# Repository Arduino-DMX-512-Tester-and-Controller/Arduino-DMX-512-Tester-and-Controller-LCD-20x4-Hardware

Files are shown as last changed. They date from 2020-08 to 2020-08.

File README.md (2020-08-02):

# **Arduino DMX-512 Tester and Controller**

## **Hardware - LCD 20x4**














***

Herramienta Open Hardware, para pruebas y control de iluminación de espectáculos a través del protocolo [DMX-512](http://es.wikipedia.org/wiki/Digital_Multiplex), ideal para hacer pruebas rápidas en instalaciones fijas o temporales de iluminación, sin la necesidad de instalar consolas de iluminación, interfaces o computadoras en ambientes al intemperie, hostiles o de difícil acceso.

***

Mas informacion en la Wiki

wiki (https://github.com/Arduino-DMX-512-Tester-and-Controller/Arduino-DMX-512-Tester-and-Controller-LCD-20x4-Firmware/wiki)

***

### **Basado en:**

- [Arduino Mega 2560 Rev-3](http://www.arduino.cc/en/Main/ArduinoBoardMega2560)
- [Librería Arduino cuatro universos DMX v0.3 - Deskontrol](http://www.deskontrol.net/blog/libreria-arduino-cuatro-universos-dmx/)
- [Libreria LCD v1.2.1 - Francisco Malpartida](https://bitbucket.org/fmalpartida/new-liquidcrystal/wiki/Home)
- [Simulación en Proteus de Arduino - Microcontrolandos](http://microcontrolandos.blogspot.mx/2012/12/arduino-componentes-para-o-proteus.html)
- [Encoder](http://www.robodosis.net/2013/01/encoder-rotativo-mecanico-con-pic16f877a_2.html)

***

- Esquemático y PCB en Proteus v8.0 SP1
- LCD de 4x20 con backlight y contraste controlado por software
- Alimentación desde USB, baterías o fuente de alimentación externa
- Encoder para navegacion entre menu
- Teclado numérico 4x4
- Interruptor de on/off
- Salida DMX desde bornera, XLR de 3 pin y XLR de 5 pin
- Leds de estado de salida DMX
- Simulación en Proteus v7.7 SP2 y v8.0 SP1
- Esquemático y PCB en Proteus v8.0 SP1
- Aclarar que para este proyecto se utilizó un Arduino Mega hecho en China
- Regulador para fuente externa, el arduino se calienta
- Bornera para salida de fuente regulada de 5V para uso general
- Led para salida de fuente regulada
- Botón de reset
- Opto acoplado a salida de dmx
- Convertidor de DC/DC para aislamiento de DMX
- SW de palanca para invertir polaridad de salida de DMX
- Jumper default eeprom en pin 9
- Driver para luz led como lampara
- SW para Key Light
- SW para Ext Light
- Espaciadores para fijación
- Leyendas de conexión
- Fuente externa, el arduino se calentaba

***

### **Changelog**

- AGREGADO   - los bordes para la union del acrílico
- ELIMINADO  - base de teclado, queda sobre el acrílico
- AGREGADO   - jack de DC para alimentacion
- AGREGADO   - tornillo entre los conectores para agregar soporte
- CORREGIDO  - bornera de voltaje lateral metera mas
- CORREGIDO  - posición de SW esta al revés, cambiar leyenda en pcb

***

### **Firmware**

- Simulacion en Proteus v7.7 SP2
- Librerias:
  - Arduino: https://geekelectronica.com/simular-arduino-con-proteus/
- Firmware v1.8 a v2.2

***

### **Simulador**

- Hardware v0.6 to v0.8
- Firmware v1.6 to v2.2

***

### **Esquematico**

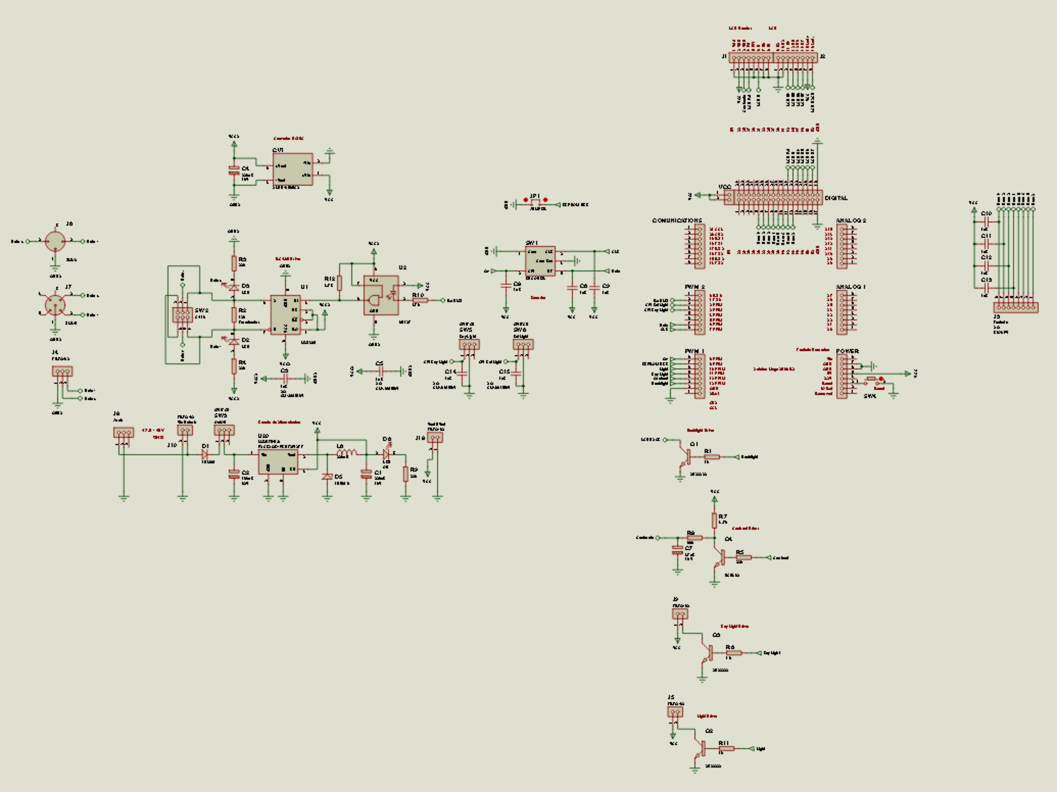
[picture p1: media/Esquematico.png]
Esquematico


***

### **PCB**

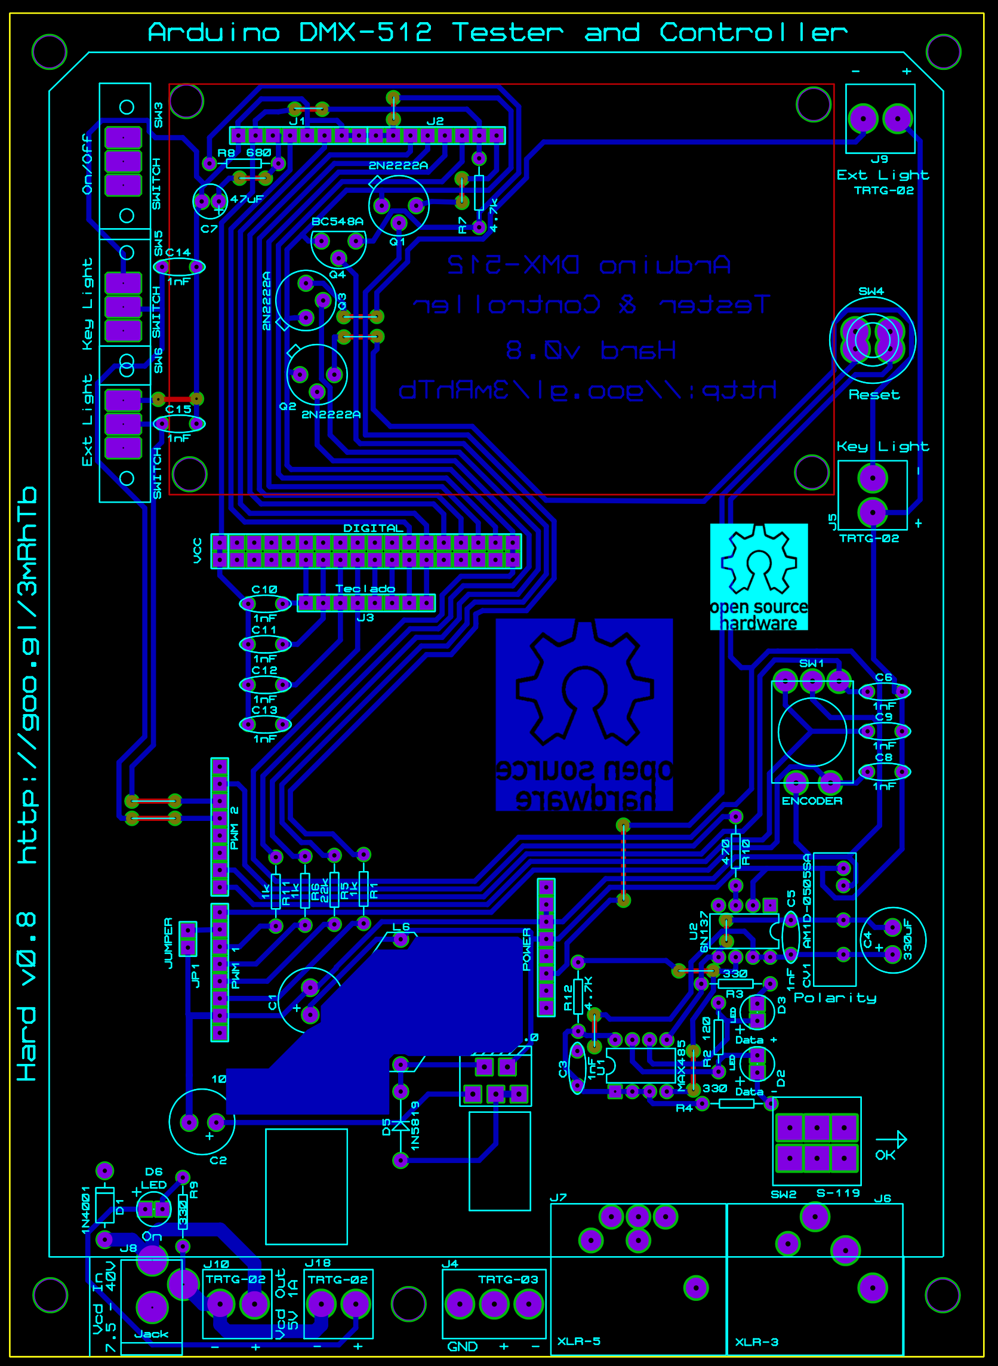
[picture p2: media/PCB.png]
PCB


***

### **Simulador**

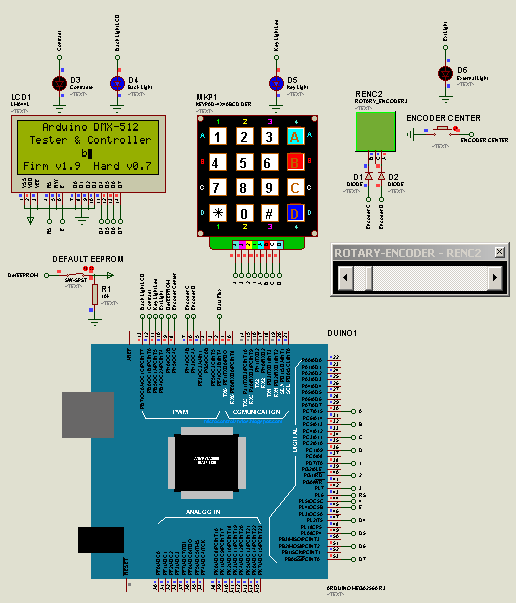
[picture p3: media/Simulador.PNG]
Simulador


***

## **Licenciamiento:**



[Open Source Hardware (OSHW) v1.0](https://github.com/Arduino-DMX-512-Tester-and-Controller/Arduino-DMX-512-Tester-and-Controller-LCD-20x4-Hardware/blob/master/LICENCE.md)

***

## **Autor:**

- Daniel Becerril
- Copyright (C) 2015

Email
Facebook (https://www.facebook.com/daniel.3514)
Facebook (https://www.facebook.com/ArduinoDMX512TesterController)
Twitter (https://twitter.com/daniel3514)
Instructables (http://www.instructables.com/id/Arduino-DMX-512-Tester-and-Controller/)
Hack a Day (https://hackaday.io/project/5342-arduino-dmx-512-tester-and-controller)
Youtube (https://www.youtube.com/watch?v=TxBHMpAWDSY)
Tech Inside (https://techinsideblog.wordpress.com/)
GitHub (https://github.com/Arduino-DMX-512-Tester-and-Controller)
Hackster (https://www.hackster.io/daniel3514/arduino-dmx-512-tester-controller-977c89)

***

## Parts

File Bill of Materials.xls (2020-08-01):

 |  |  |  |  |  | USD | USD
 |  |  |  |  |  |  | $88.72
Category | Quantity | References | Value | Provider | Stock Code | Unit Cost | Total Cost
Capacitors | 2 | C1,C4 | 330uF/16V | www.agelectronica.com | CE-330/16V | $0.09 | $0.18
Capacitors | 1 | C2 | 100uF/63V | www.agelectronica.com | CE-100/63V | $0.09 | $0.09
Capacitors | 11 | C3,C5-C6,C8-C15 | 1nF | www.agelectronica.com | CM-.001/50V | $0.07 | $0.77
Capacitors | 1 | C7 | 47uF/16V | www.agelectronica.com | CE-47/16V | $0.09 | $0.09
Resistors | 3 | R1,R6,R11 | 1k | www.agelectronica.com |  | $0.04 | $0.12
Resistors | 1 | R2 | 120 | www.agelectronica.com |  | $0.04 | $0.04
Resistors | 3 | R3-R4,R9 | 330 | www.agelectronica.com |  | $0.04 | $0.12
Resistors | 1 | R5 | 22k | www.agelectronica.com |  | $0.04 | $0.04
Resistors | 1 | R7 | 4.7k | www.agelectronica.com |  | $0.04 | $0.04
Resistors | 1 | R8 | 680 | www.agelectronica.com |  | $0.04 | $0.04
Resistors | 1 | R10 | 470 | www.agelectronica.com |  | $0.04 | $0.04
Resistors | 1 | R12 | 4.7K | www.agelectronica.com |  | $0.04 | $0.04
Integrated Circuits | 1 | U1 | MAX485 | www.agelectronica.com | SP485CS | $1.18 | $1.18
Integrated Circuits | 1 | U2 | 6N137 | es.aliexpress.com | 6N137 | $0.39 | $0.39
Integrated Circuits | 1 | U20 | LM2575-5.0 | www.agelectronica.com | LM2575T-5.0 | $2.21 | $2.21
Transistors | 3 | Q1-Q3 | 2N2222A | www.agelectronica.com | NTE123AP | $0.83 | $2.49
Transistors | 1 | Q4 | BC548A | www.agelectronica.com | NTE199 | $1.03 | $1.03
Diodes | 1 | D1 | 1N4001 | www.agelectronica.com | 1N4001 | $0.05 | $0.05
Diodes | 3 | D2-D3,D6 | LED | www.agelectronica.com | LED-R3D-AD-R30 | $0.04 | $0.12
Diodes | 1 | D5 | 1N5819 | www.agelectronica.com | 1N5819 | $0.09 | $0.09
Miscellaneous | 11 | ANALOG 1-ANALOG 2,COMUNICATIONS,DIGITAL-J2,POWER-PWM 2,SW4,VCC | HEADER-1 | www.agelectronica.com | HEADER-1 | $0.12 | $1.32
Miscellaneous | 1 | CV1 | AM1D-0505SA | http://www.tme.eu/en/details/am1d-0505sz/dcdc-converters/aimtec/ | AM1D-0505SA | $3.56 | $3.56
Miscellaneous | 1 | J3 | EIS-8PV | www.agelectronica.com |  | $0.11 | $0.11
Connectors | 1 | J4 | TRTG-03 | www.steren.com.mx | TRTG-03 | $0.68 | $0.68
Connectors | 4 | J5,J9-J10,J18 | TRTG-02 | www.steren.com.mx | TRTG-02 | $0.45 | $1.80
Miscellaneous | 1 | J6 | XLR-3 | http://www.newark.com/webapp/wcs/stores/servlet/Search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 | AMPHENOL JACK, XLR, PCB, HORIZ, 3WAY | $1.66 | $1.66
Miscellaneous | 1 | J7 | XLR-5 | http://www.newark.com/amphenol/ac5fah-au-b/jack-xlr-pcb-horiz-5way/dp/86R1202?ost=AC5FAH-AU-B | AMPHENOL XLR 5 pole female, Horizontal PCB, Gold Plated contacts, Bulk pack | $3.60 | $3.60
Miscellaneous | 1 | JP1 | JUMPER | www.agelectronica.com | HEADER-1 | $0.12 | $0.12
Miscellaneous | 1 | JP1 | JUMPER | www.agelectronica.com | JUMPER | $0.09 | $0.09
Coils | 1 | L6 | 330uH | www.agelectronica.com | SDR1806-331KL | $0.73 | $0.73
Switches | 1 | SW1 | ENCODER | es.aliexpress.com | KY040 | $4.50 | $4.50
Switches | 1 | SW2 | S-119 | www.steren.com.mx | S-119 | $0.45 | $0.45
Switches | 3 | SW3,SW5-SW6 | SWITCH | www.steren.com.mx | CS-122 | $0.34 | $1.02
Miscellaneous | 1 | Arduino Mega 2560 or compatible |  | https://store.arduino.cc |  | $39.45 | $39.45
Switches | 1 | KeyBoard 4x4 matrix |  | es.aliexpress.com |  | $0.16 | $0.16
Miscellaneous | 14 | Metal hexagonal M3 M3 tornillo PCB separadores Standoff 8 mm |  | es.aliexpress.com |  | $0.10 | $1.40
LCD | 1 | 20x4 White on Blue Character LCD with Backlight |  | http://www.gravitech.us/20chbllcd.html |  | $17.95 | $17.95
Miscellaneous | 2 | BASE 8 PINS P/C.I. MAQUINADA |  | http://www.agelectronica.com/Virtual_Shop/index.asp | 8PF | $0.11 | $0.22
Miscellaneous | 1 | TIRA DE LEDS 3528 BCO PUR SUPER BRILLANTE PCB BCO 10cm |  | http://www.agelectronica.com/Virtual_Shop/index.asp | FSL-3528W300-N/W-SB | $0.73 | $0.73

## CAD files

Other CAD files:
Open Hardware Logo/logo open hardware.dwg

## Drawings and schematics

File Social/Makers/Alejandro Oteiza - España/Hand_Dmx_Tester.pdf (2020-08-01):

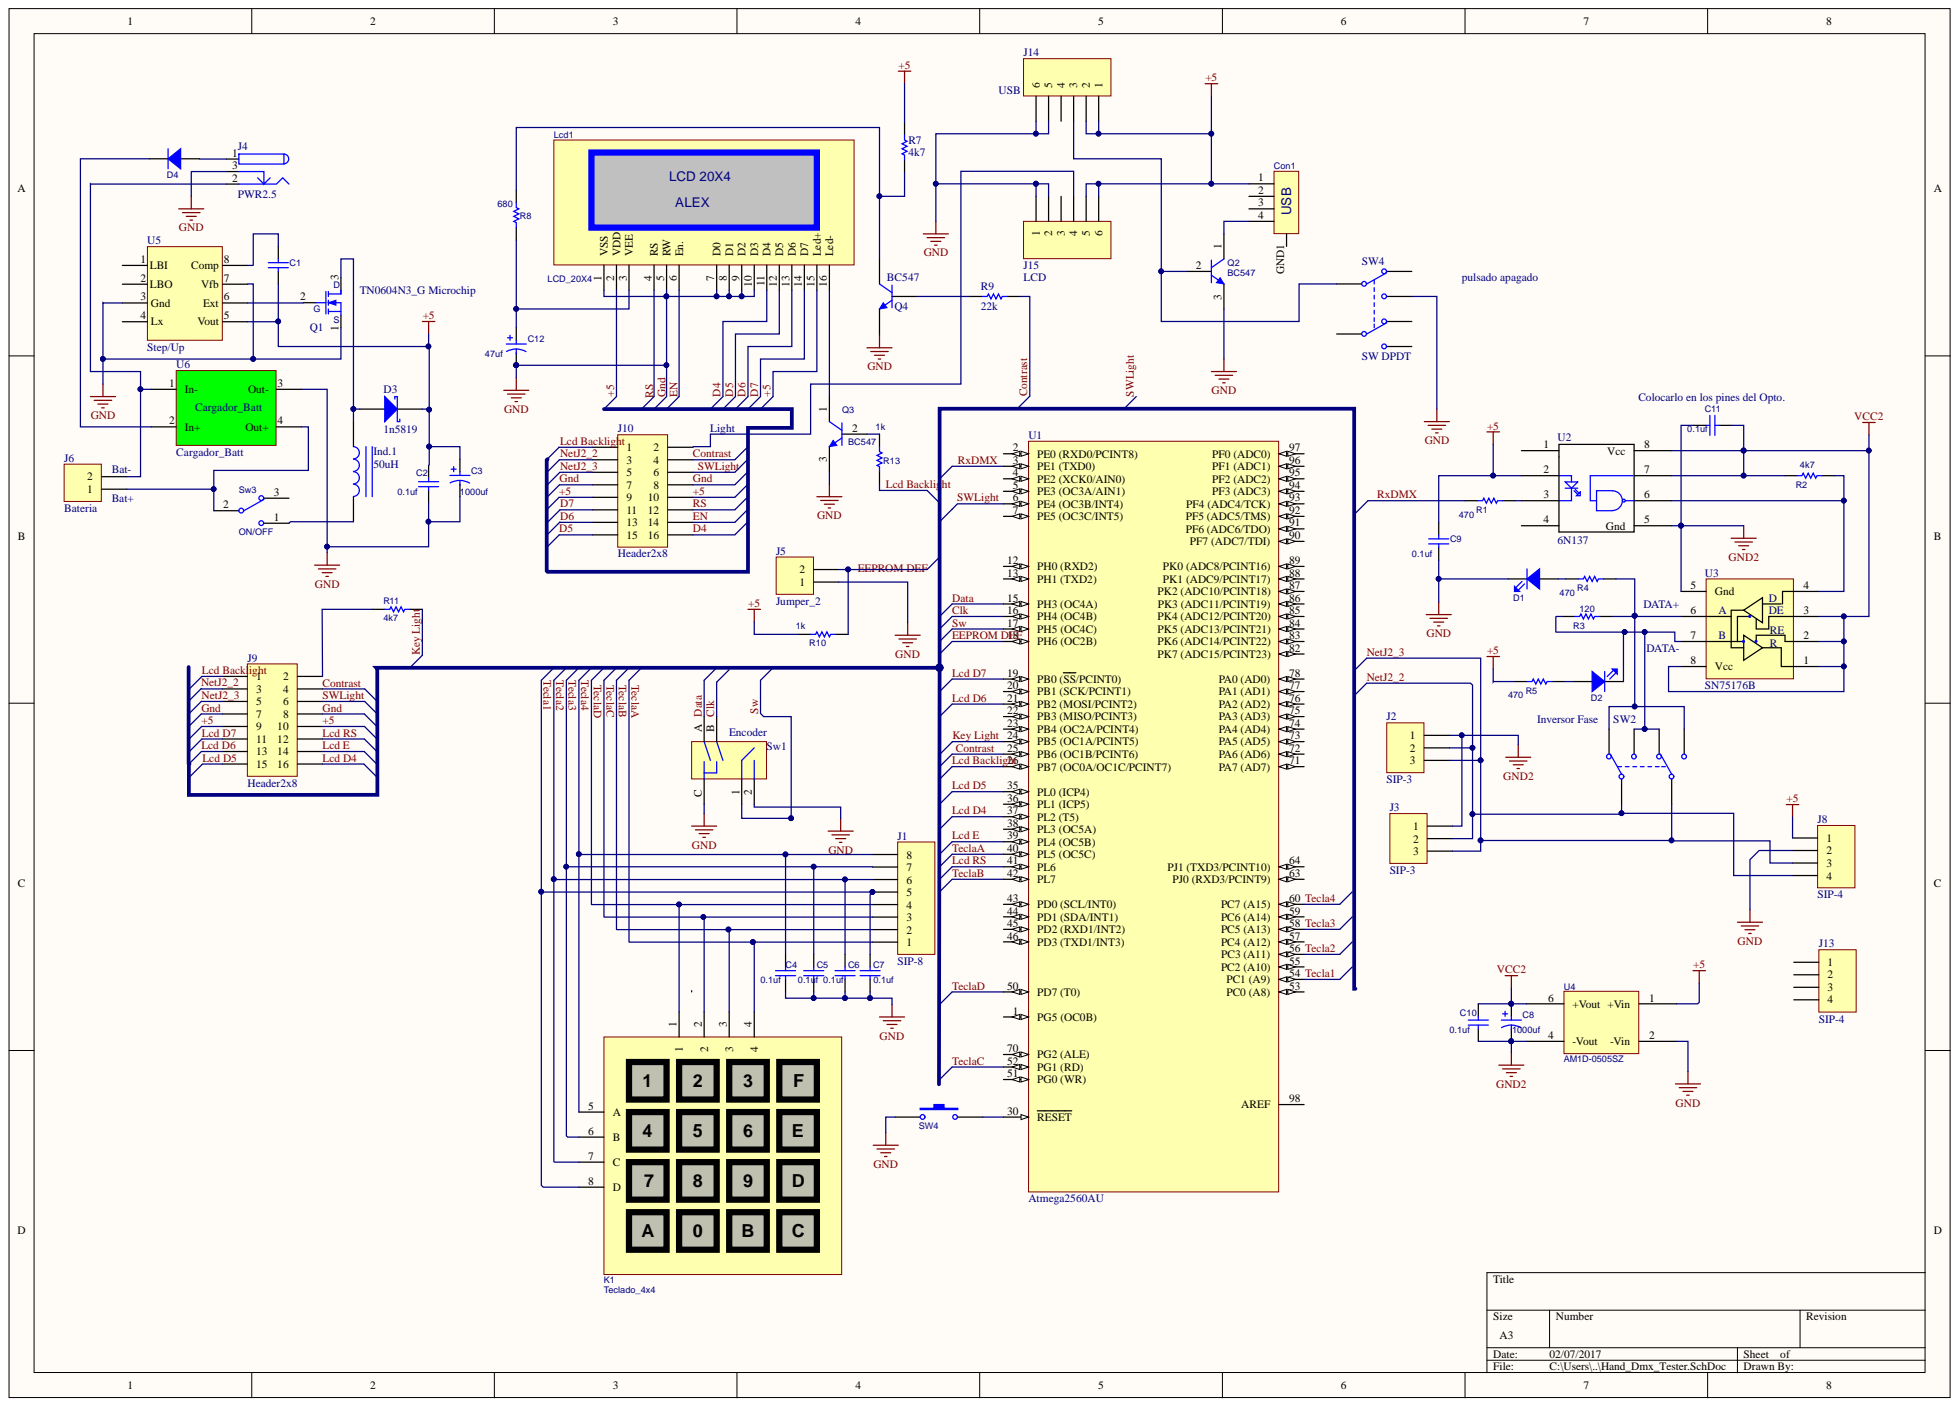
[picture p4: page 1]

Colocarlo en los pines del Opto.

Gnd 5

B | RE | | 2
Vcc 8 | R | 1

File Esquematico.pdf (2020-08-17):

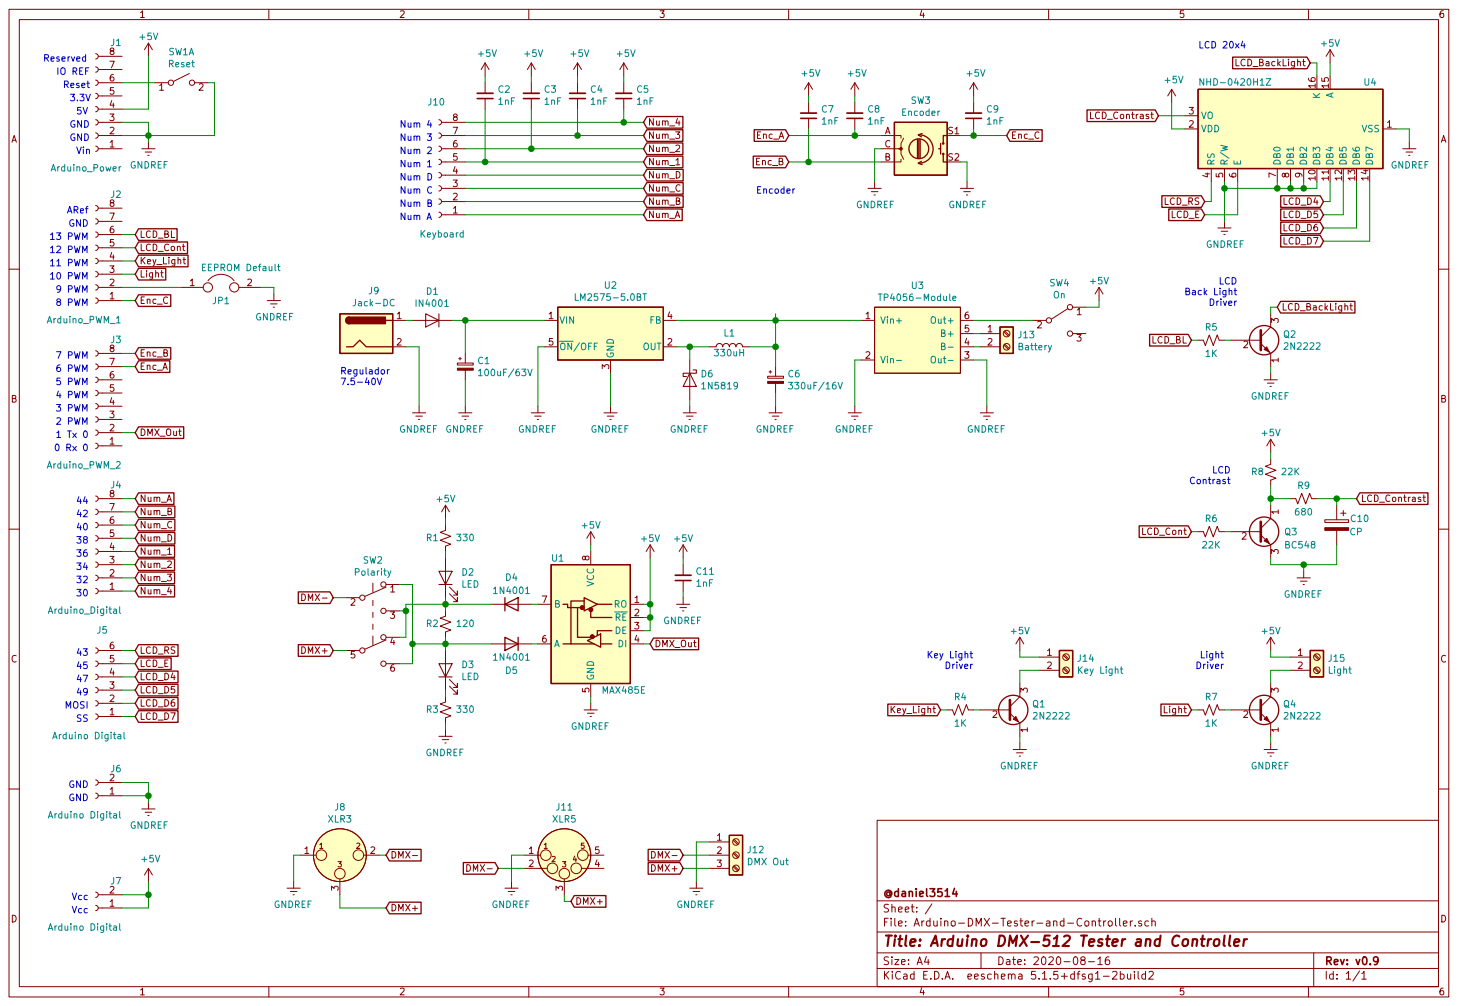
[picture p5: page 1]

Back Light Driver LCD 20x4 Regulador 7.5-40V

Num 4 Num 3 Num 2 Num 1 Num D

Id: 1/1 Title: Arduino DMX-512 Tester and Controller File: Arduino-DMX-Tester-and-Controller.sch Sheet: / @daniel3514

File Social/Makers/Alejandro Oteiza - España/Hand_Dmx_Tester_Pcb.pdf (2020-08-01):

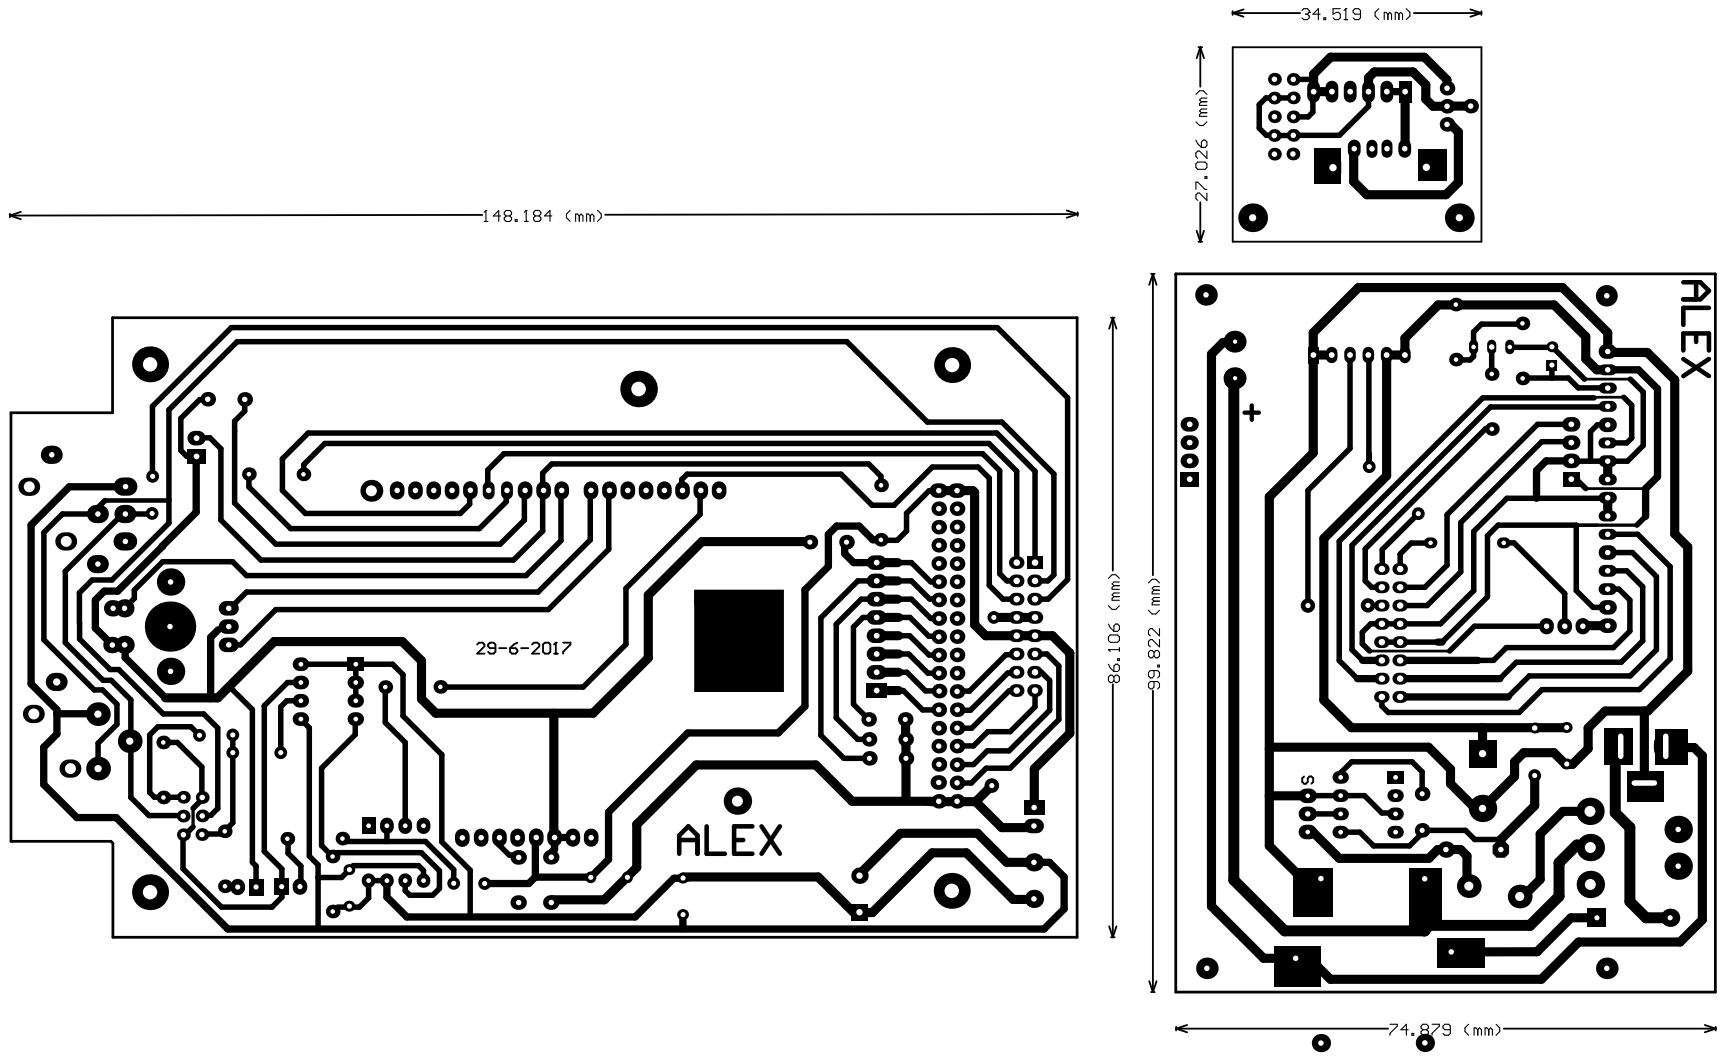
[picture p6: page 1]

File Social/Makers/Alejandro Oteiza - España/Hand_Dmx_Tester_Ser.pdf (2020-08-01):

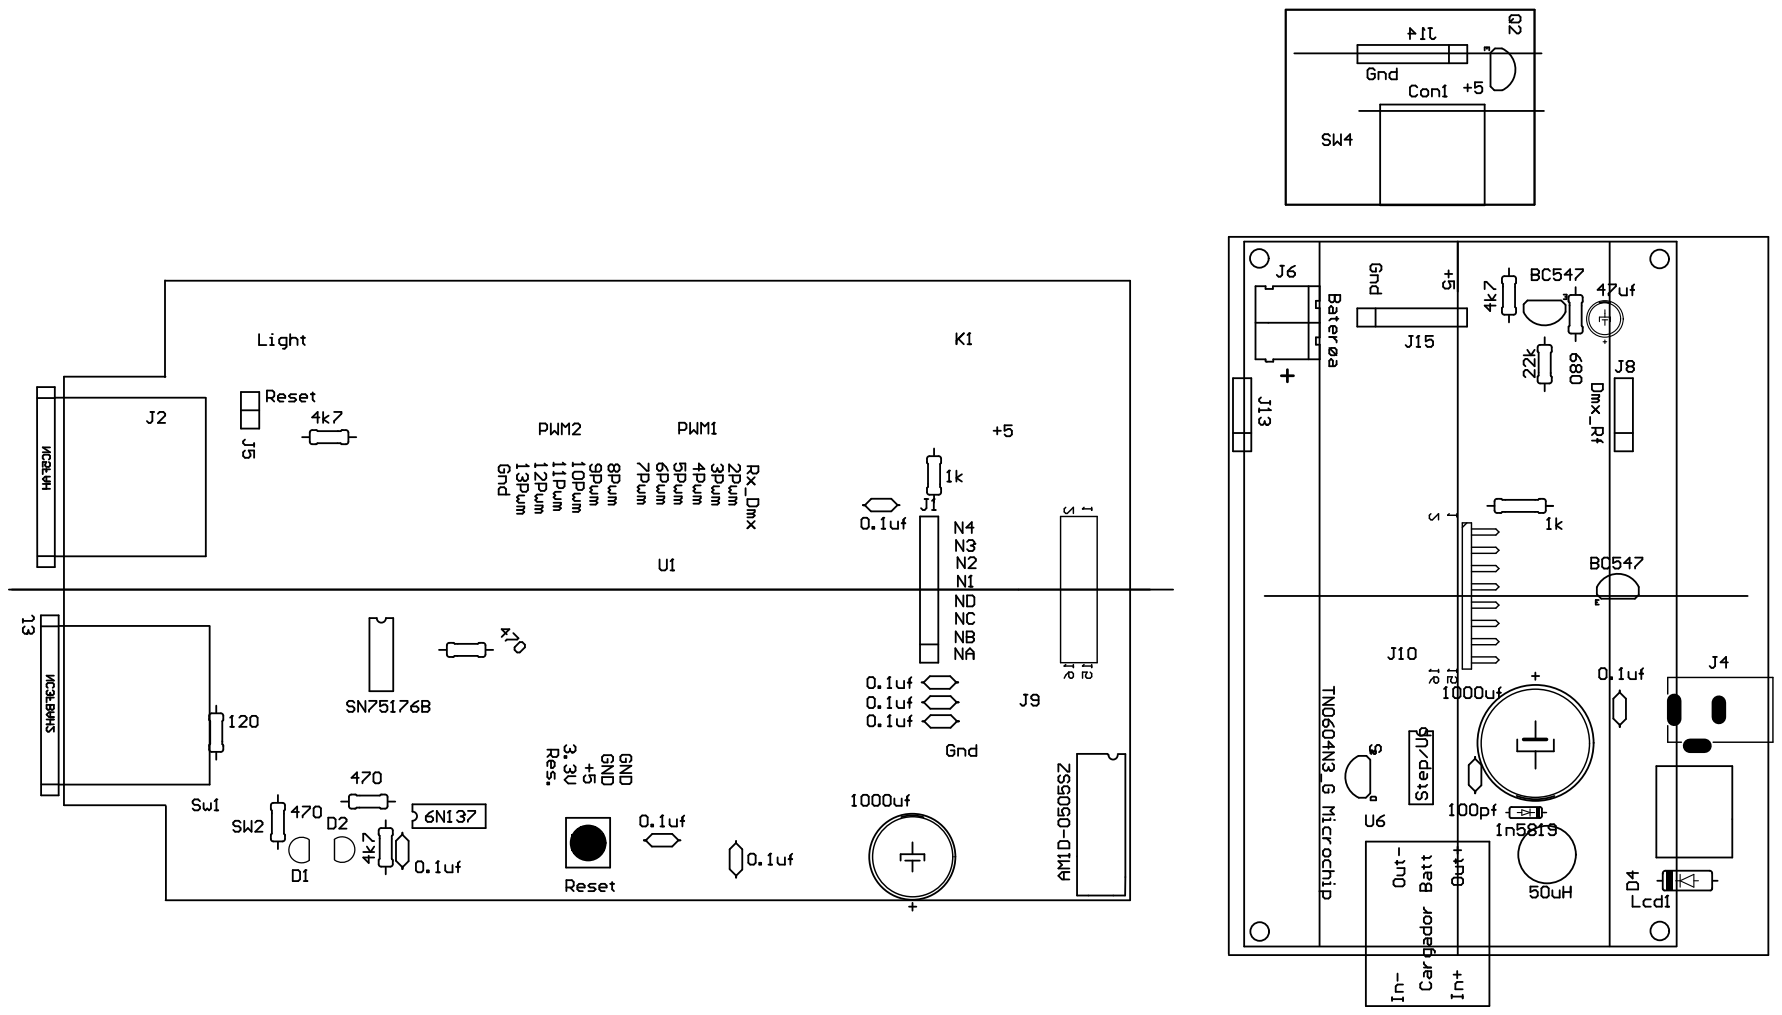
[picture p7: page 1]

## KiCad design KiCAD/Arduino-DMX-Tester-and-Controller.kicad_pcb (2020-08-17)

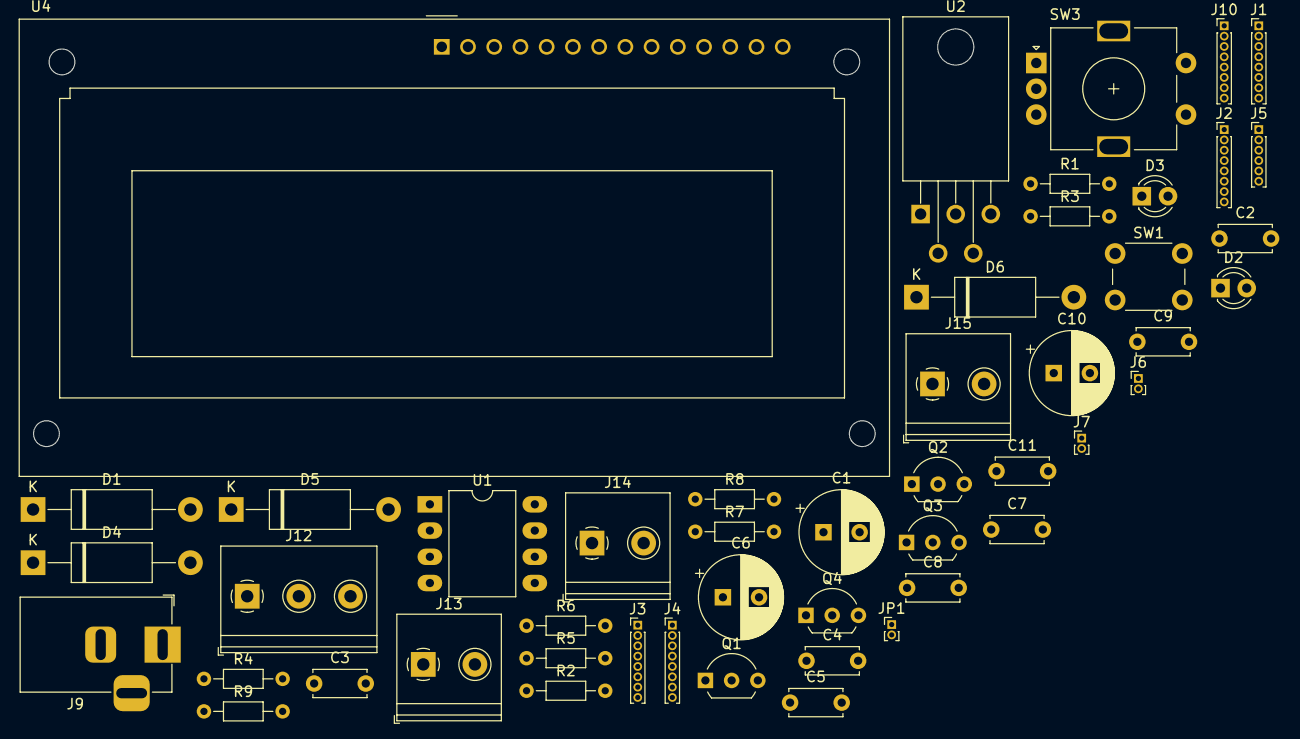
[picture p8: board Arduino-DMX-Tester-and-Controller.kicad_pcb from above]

Board: 2 copper layers, 49 parts (0 on the bottom side), 44 nets, no tracks yet.

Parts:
C1: 100uF/63V; CP_Radial_D8.0mm_P3.50mm
C2, C3, C4, C5, C7, C8, C9, C11: 1nF; C_Disc_D5.0mm_W2.5mm_P5.00mm
C6: 330uF/16V; CP_Radial_D8.0mm_P3.50mm
C10: 47uF/16V; CP_Radial_D8.0mm_P3.50mm
D1, D4, D5: 1N4001; D_DO-15_P15.24mm_Horizontal
D2, D3: LED; LED_D3.0mm
D6: 1N5819; D_DO-15_P15.24mm_Horizontal
J1, J2, J3, J4, J10: Pin Header 8; PinHeader_1x08_P1.00mm_Vertical
J5: Pin Header 6; PinHeader_1x06_P1.00mm_Vertical
J6, J7: Pin Header 2; PinHeader_1x02_P1.00mm_Vertical
J9: Jack-DC; BarrelJack_Horizontal
J12: Terminal Screw 3; TerminalBlock_Philmore_TB133_1x03_P5.00mm_Horizontal
J13, J14, J15: Terminal Screw 2; TerminalBlock_Philmore_TB132_1x02_P5.00mm_Horizontal
JP1: Jumper; PinHeader_1x02_P1.00mm_Vertical
Q1, Q2, Q4: 2N2222; TO-92L_Inline_Wide
Q3: BC548; TO-92L_Inline_Wide
R1, R3: 330; R_Axial_DIN0204_L3.6mm_D1.6mm_P7.62mm_Horizontal
R2: 120; R_Axial_DIN0204_L3.6mm_D1.6mm_P7.62mm_Horizontal
R4, R5, R7: 1K; R_Axial_DIN0204_L3.6mm_D1.6mm_P7.62mm_Horizontal
R6, R8: 22K; R_Axial_DIN0204_L3.6mm_D1.6mm_P7.62mm_Horizontal
R9: 680; R_Axial_DIN0204_L3.6mm_D1.6mm_P7.62mm_Horizontal
SW1: Micro Switch; SW_PUSH_6mm
SW3: Encoder; RotaryEncoder_Alps_EC11E-Switch_Vertical_H20mm
U1: MAX485E; DIP-8_W10.16mm_LongPads
U2: LM2575-5.0BT; TO-220-5_P3.4x3.8mm_StaggerEven_Lead7.13mm_TabDown
U4: NHD-0420H1Z; LM16255

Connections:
+5V: C2.2, C3.2, C4.2, C5.2, C7.2, C8.2, C9.2, C11.2, J1.4, J7.1, J7.2, J14.1, J15.1, R1.2, R8.2, U1.1, U1.2, U1.3, U1.8, U4.2
DMX_Out: J3.2, U1.4
Enc_A: C8.1, J3.7, SW3.A
Enc_B: C7.1, J3.8, SW3.B
Enc_C: C9.1, J2.1, SW3.S1
GNDREF: C1.2, C6.2, C10.2, C11.1, D6.2, J1.2, J1.3, J6.1, J6.2, J9.2, J12.1, JP1.2, Q1.1, Q2.1, Q3.3, Q4.1, R3.1, SW1.2, SW3.C, SW3.S2, U1.5, U2.3, U2.5, U4.1, U4.5, U4.7, U4.8, U4.9, U4.10
Key_Light: J2.4, R4.1
LCD_BL: J2.6, R5.1
LCD_Cont: J2.5, R6.1
LCD_Contrast: C10.1, R9.2, U4.3
LCD_D4: J5.4, U4.11
LCD_D5: J5.3, U4.12
LCD_D6: J5.2, U4.13
LCD_D7: J5.1, U4.14
LCD_E: J5.5, U4.6
LCD_RS: J5.6, U4.4
Light: J2.3, R7.1
unnamed: C1.1, D1.1, U2.1
unnamed: C6.1, U2.4
unnamed: D1.2, J9.1
unnamed: D2.1, D4.2, R2.2
unnamed: D2.2, R1.1
unnamed: D3.1, R3.2
unnamed: D3.2, D5.1, R2.1
unnamed: D4.1, U1.7
unnamed: D5.2, U1.6
unnamed: D6.1, U2.2
unnamed: J1.6, SW1.1
unnamed: J2.2, JP1.1
unnamed: J14.2, Q1.3
unnamed: J15.2, Q4.3
unnamed: Q1.2, R4.2
unnamed: Q2.2, R5.2
unnamed: Q3.1, R8.1, R9.1
unnamed: Q3.2, R6.2
unnamed: Q4.2, R7.2
Num_1: C2.1, J4.4, J10.5
Num_2: C3.1, J4.3, J10.6
Num_3: C4.1, J4.2, J10.7
Num_4: C5.1, J4.1, J10.8
Num_A: J4.8, J10.1
Num_B: J4.7, J10.2
Num_C: J4.6, J10.3
Num_D: J4.5, J10.4

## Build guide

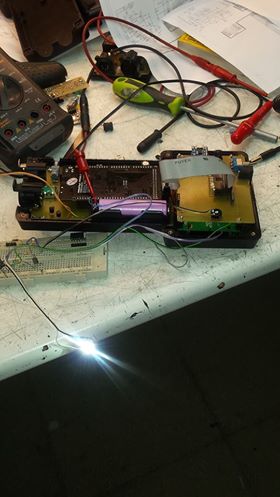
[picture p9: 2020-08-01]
Social/Makers/Alejandro Oteiza - España/19553531_942604822549015_779256840_n.jpg

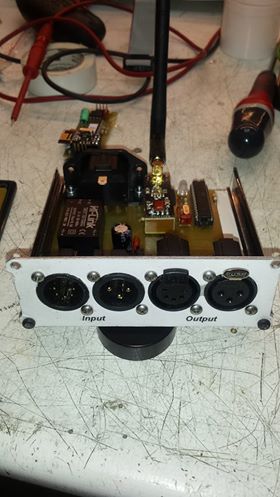
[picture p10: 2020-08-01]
Social/Makers/Alejandro Oteiza - España/19551148_942507199225444_1165154748_n.jpg

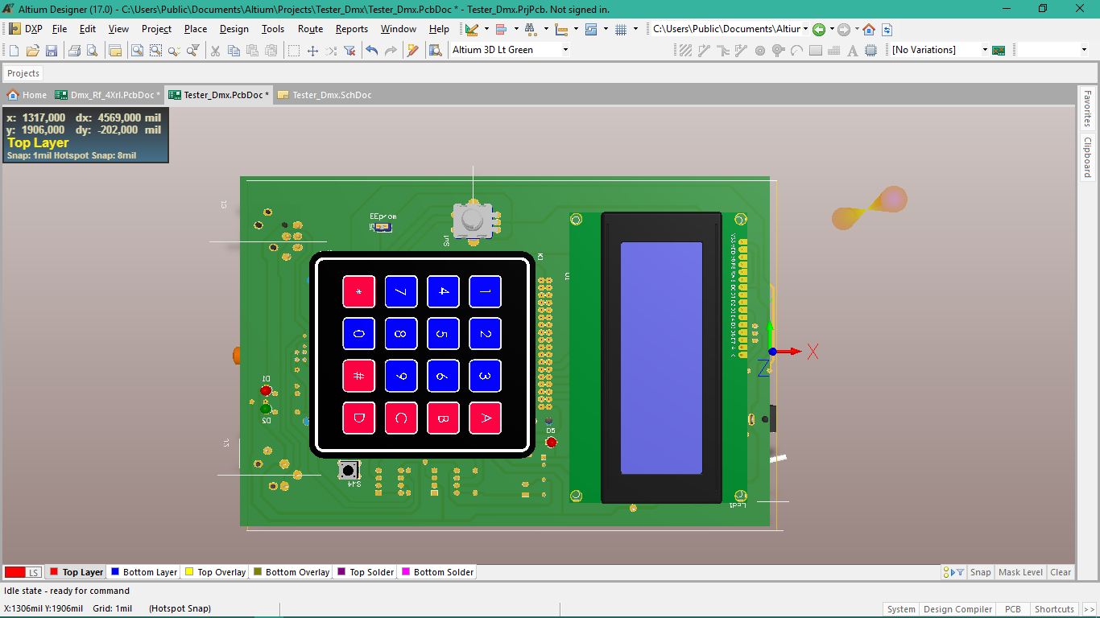
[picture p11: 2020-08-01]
Social/Makers/Alejandro Oteiza - España/18451892_912503118892519_416876039_o.png

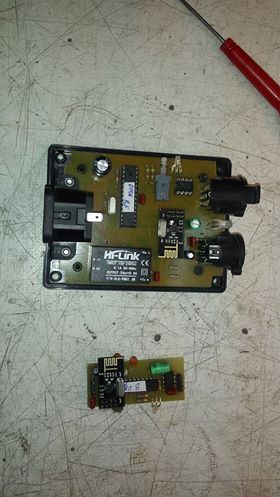
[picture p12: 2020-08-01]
Social/Makers/Alejandro Oteiza - España/19551025_942504532559044_1623747912_n.jpg

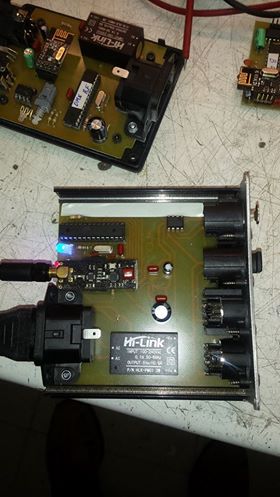
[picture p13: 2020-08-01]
Social/Makers/Alejandro Oteiza - España/19512203_942509109225253_159774900_n.jpg

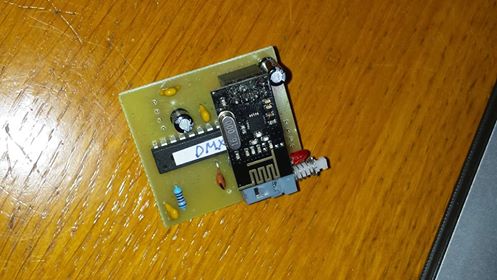
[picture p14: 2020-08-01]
Social/Makers/Alejandro Oteiza - España/19477881_941206502688847_495365207_n.jpg

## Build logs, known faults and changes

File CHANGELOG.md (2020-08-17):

# **Hardware**

***

## **Changelog**

***

### v0.9
- **FIRMWARE**   - v1.8 a v2.1

#### 16-ago-20
- **AGREGADO**   - diodos de proteccion para MAX485
- **ELIMINADO**  - Optoacoplado
- **ELIMINADO**  - sw light, se queda por software
- **ELIMINADO**  - sw key light, se queda por software
- **ELIMINADO**  - C4, capacitor de DC a DC
- **ELIMINADO**  - Convertidor de DC a DC
- **AGREGADO**   - Modulo TP4056 para carga de bateria
- **ELIMINADO**  - J18
- **ELIMINADO**  - D6, R9, led on
- **ELIMINADO**  - TRTG-02 Vin Bateria
- **CORREGIDO**  - D1, al la entrada de Vin
- **CORREGIDO**  - Esquematico a KiCAD
***

### v0.8
- **FIRMWARE**   - v1.8 a v2.1
- **AGREGADO**   - los bordes para la union del acrílico
- **ELIMINADO**  - base de teclado, queda sobre el acrílico
- **AGREGADO**   - jack de DC para alimentacion
- **AGREGADO**   - tornillo entre los conectores para agregar soporte
- **CORREGIDO**  - bornera de voltaje lateral metera mas
- **CORREGIDO**  - posición de SW esta al revés, cambiar leyenda en pcb

***

### v0.7
- **FIRMWARE**   - v1.8 a v2.1
- **AGREGADO**   - SW para Key Light
- **AGREGADO**   - SW para Ext Light
- **AGREGADO**   - Espaciadores para fijación
- **AGREGADO**   - Leyendas de conexión
- **AGREGADO**   - Fuente externa, el arduino se calentaba
- **CORREGIR**   - marcar en board edge los agujeros de los XLR
- **CORREGIR**   - los XLR quedan chuecos
- **CORREGIR**   - Encoder, separar los agujeros están muy juntos
- **CORREGIR**   - separar bornera de key light de lcd, esta muy junta
- **CORREGIR**   - pads de puentes muy chicos
- **CORREGIR**   - pads de botón de reset muy chicos
- **CORREGIR**   - subir logo de Open Hardware
- **CORREGIR**   - texto de about, hacerlo mas grueso
- **CORREGIR**   - bornera de voltaje lateral metera mas
- **CORREGIR**   - acostar C7
- **CORREGIR**   - tornillos de LCD no coinciden
- **CORREGIR**   - jumper de reset, poner pullup, el pin no tiene interno
- **CORREGIR**   - posición de SW esta al revés, cambiar leyenda en pcb

***
 
### v0.6
- **FIRMWARE**   - v1.7
- **AGREGADO**   - regulador para fuente externa, el arduino se calienta
- **AGREGADO**   - bornera para salida de fuente regulada de 5V para uso general
- **AGREGADO**   - led para salida de fuente regulada
- **AGREGADO**   - botón de reset
- **AGREGADO**   - opto acoplado a salida de dmx
- **AGREGADO**   - convertidor de DC/DC para aislamiento de DMX
- **AGREGADO**   - SW de palanca para invertir polaridad de salida de DMX
- **AGREGADO**   - Al encoder capacitores para rebote
- **AGREGADO**   - jumper default eeprom en pin 9
- **AGREGADO**   - driver para luz led como lampara
- **AGREGADO**   - capacitores al teclado para rebote
- **AGREGADO**   - logo de Open Hardware
- **CORREGIDO**  - se eliminan los cursores, los remplaza el encoder
- **CORREGIDO**  - se saco el encoder de la placa original y se solda directo a la placa
- **CORREGIDO**  - se elimina el data I/O
- CORREGIDO  - se quito la entrada al Arduino desde el MAX485, causa problemas al cargar el programa
- **CORREGIDO**  - Las bases de los CI se cambiaron a maquinadas
- **AGREGADO**   - Optoacoplamiento
                - http://www.mathertel.de/Arduino/DMXShield.aspx
- **CHECAR**     - en firmware que el encoder DT y CLK que sean pullup

***

### v0.5
- **FIRMWARE**  - v1.6 a 1.7
- **CORREGIDO** - potenciómetro por encoder
- **CORREGIDO** - etapa de potencia para contraste
- **AGREGADO** 	- Luz para el teclado y cursores
- **AGREGADO**  - Etapa de potencia para luz de teclado
- **AGREGADO**  - Contraste por PWM
                - http://www.pcbheaven.com/circuitpages/PWM_LCD_Contrast_Control/

***

### v0.4
- **FIRMWARE**  - v0.9 a v1.3
- **CORREGIDO** - hacer más grandes los pads del SW
- **CORREGIDO** - quitar parte de abajo del soporte del teclado estorba con el flex del teclado
- **CORREGIDO** - recorrida la bornera de la conexión dmx hacia el arduino, queda más centrada
- **CORREGIDO** - acercar la base del mx485 al borde de la placa para que el teclado no estorbe
- **CORREGIDO** - agregar un diodo rectificador a la entrada de la batería
- **CORREGIDO** - se hizo más chico el puente que estaba dentro del área del arduino
- **CORREGIDO** - los datos de la salida están al revés
- **AGREGADO**  - interconectados los pines del arduino de vcc y gnd faltantes
- **AGREGADO**  - la leyenda open hardware a bottom

***

### v0.3 
- **FIRMWARE**  - v0.9 a v1.3
- **AGREGADO**  - backlight a pin 13 para efecto en el lcd mientras se actualiza
- **AGREGADO**  - control de contraste desde software
- **AGREGADO**  - control de back light desde software
- **CORREGIR**  - agregar capacitores al backlight y al contraste, parpadea con baja frecuencia
- **CORREGIR**  - acercar el potenciómetro a los pads y marcar el pad del centro
- **CORREGIR**  - acercar la base del mx485 al borde de la placa para que el teclado no estorbe
- **CORREGIR**  - la placa del teclado tiene mal ubicado el header de abajo donde pasa el flex del teclado
- **CORREGIR**  - agregar un diodo rectificador a la entrada de la batería
- **CORREGIR**  - agregar serigrafía a top en el pcb
- **CORREGIR**  - hacer más grandes los pads del SW
- **CORREGIR**  - quitar parte de abajo del soporte del teclado estorba con el flex del teclado
- **CORREGIR**  - los datos de la salida están al revés

***

### v0.2
- **FIRMWARE**  - v0.0 a v0.8
- **AGREGADO**  - control de contraste desde software
- **AGREGADO**  - control de back light desde software

***

### v0.1
- **FIRMWARE**  - v0.0 a v0.8
- **CORREGIDO** - no se necesita el led on, la pantalla ya tiene un led (el led ON se retira, los leds de la salida del dmx indican que está activo)
- **CORREGIDO** - no hay botón de reset (no se requiere el botón de reset, hay un switch de on off)
- **CORREGIDO** - quitar botón SW de encendido (se cambió por un switch deslizable)
- **CORREGIDO** - base de teclado, darle más soporte (no requiere más soporte)
- **CORREGIDO** - eliminar la fuente de alimentacion regulada (se eliminó la fuente regulada)
- **CORREGIDO** - quitar de los conectores USB y power del arduino, las conexiones de arriba, no permiten que cierre bien el arduino (se reubicaron los componentes)
- **CORREGIDO** - pasar los conectores a la parte de abajo, pesa mucho la placa (los conectores se pasaron a la parte de abajo)
- **CORREGIDO** - agregar capacitores cerámicos a los botones para el rebote (agregados, cerámicos 104, mejoro la estabilidad en la lectura)
- **CORREGIDO** - se cambió el conector XLR de 3 pin por conector amphenol de 3 y 5 pin, son más resistentes
- **CORREGIDO** - los leds de la salida del DMX se cambiaron a la parte de abajo y viendo hacia abajo, molestaba a la vista
- **CORREGIDO** - el pcb se redujo
- AGREGADO  - etapa de potencia para controlar el back light del LCD
- **AGREGADO**  - conexión para baterías
- AGREGADO  - header para completar la conexión del arduino, estaba incompleta

***

### v0.0 
- **FIRMWARE**  - v0.0 a v0.8
- **CORREGIR**  - no se necesita el led on, la pantalla ya tiene un led
- **CORREGIR**  - no hay botón de reset
- **CORREGIR**  - quitar botón SW de encendido
- **CORREGIR**  - agregar canon XLR de 5 pin
- **CORREGIR**  - base de teclado, darle más soporte
- **CORREGIR**  - eliminar la fuente de alimentacion regulada, arduino ya tiene una fuente regulada
- **CORREGIR**  - quitar de los conectores USB y power del arduino, las conexiones de arriba, no permiten que cierre bien el arduino
- **CORREGIR**  - pasar los conectores a la parte de abajo, pesa mucho la placa
- **CORREGIR**  - agregar capacitores cerámicos a los botones para el rebote

***

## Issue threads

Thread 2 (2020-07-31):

no hay botón de reset

daniel3514, 2020-07-31:

daniel3514, 2020-07-31:
no se requiere el botón de reset, hay un switch de on off

Closed 2020-07-31.

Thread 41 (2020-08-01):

jumper de reset, poner pullup, el pin no tiene interno

daniel3514, 2020-08-01:

Closed 2020-08-01.

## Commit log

2020-07-31 update
    se quitaron los temporales de proteus y se agrego la importacion del simulador a v8.0
2020-07-31 remplazo de archivo de proteus a v0.1
2020-07-31 Archivo de proteus actualizado a v8.2
2020-07-31 actualizacion de imagenes para README
2020-08-01 archivo de proteus a v8.2
2020-08-01 agregado pdf de preprensa
2020-08-01 agregado fotos de armado
2020-08-01 Simulador actualizado
    [DMX Controller - Proteus v77.DSN]
2020-08-01 Agregados carpeta de logos y social
    [Alex_1_5_2017.SchLib, Hand_Dmx_Tester.PrjPcb, Hand_Dmx_Tester.SchDoc]
2020-08-01 Esquematico y pcb capturas
2020-08-01 fotos de armado eliminadas
2020-08-01 Create Bill of Materials.xls
    [Bill of Materials.xls]
2020-08-01 media update, sumulador update
    [DMX Controller - Proteus v77.DSN]
2020-08-01 Simulador en v80
    [DMX Controller - Proteus v77.DSN]
2020-08-01 update docs
    [Bill of Materials.xls]
2020-08-01 PCB media update
2020-08-01 archivo de proteus firmato v8.21

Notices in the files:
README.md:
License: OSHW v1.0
